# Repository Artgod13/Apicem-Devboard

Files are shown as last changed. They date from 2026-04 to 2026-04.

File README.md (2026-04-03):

# Description
The Apicem Devboard is a Devboard designed by me for Hack Club. Currently it uses a RP2040 MCU, USB-C Power, 16 Mb Flash Storage, Reset Button, Power Indication LED, and a Neo Pixel Status LED. The board was designed to handle 0.6 amps of power. All of these features were added with what is essential in a board in mind. This board was designed to be like a Pi-Pico but way beefier and look cooler. In theory it should be exactly the same dimensions as a Pi-Pico and it uses the same MCu as the Pi-Pico. This board is named "Apicem" as that's latin for "vertex" or "peak" showing how this board is the peak of it's kind.



## Schematic


## PCB





## 3D Images



## My Documented Journey
See [My Journal](./JOURNAL.md)

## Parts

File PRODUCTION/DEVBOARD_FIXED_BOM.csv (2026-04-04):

Designator | Footprint | Value | LCSC Part #
C1 | C_0402_1005Metric | 1uF | C15849
C2 | C_0402_1005Metric | 1uF | C15849
C3 | C_0402_1005Metric | 100nF | C1525
C4 | C_0402_1005Metric | 100nF | C1525
C5 | C_0402_1005Metric | 100nF | C1525
C6 | C_0402_1005Metric | 100nF | C1525
C7 | C_0402_1005Metric | 100nF | C1525
C8 | C_0402_1005Metric | 100nF | C1525
C9 | C_0402_1005Metric | 100nF | C1525
C10 | C_0402_1005Metric | 100nF | C1525
C11 | C_0402_1005Metric | 100nF | C1525
C12 | C_0402_1005Metric | 100nF | C1525
C13 | C_0402_1005Metric | 100nF | C1525
C14 | C_0402_1005Metric | 100nF | C1525
C15 | C_0402_1005Metric | 100nF | C1525
C16 | C_0402_1005Metric | 33pF | C1647
C17 | C_0402_1005Metric | 33pF | C1647
C18 | C_0603_1608Metric | 10uF | C19702
C19 | C_0603_1608Metric | 10uF | C19702
R1 | R_0402_1005Metric | 27 | C25190
R2 | R_0402_1005Metric | 27 | C25190
R3 | R_0402_1005Metric | 5.1K | C25905
R4 | R_0402_1005Metric | 5.1K | C25905
R5 | R_0402_1005Metric | 10K | C25804
R6 | R_0402_1005Metric | 10K | C25804
R7 | R_0402_1005Metric | 1K | C11702
R8 | R_0402_1005Metric | 1K | C11702
R9 | R_0603_1608Metric | 330 | C23138
D1 | LED_0603_1608Metric | LED | C72043
D2 | LED_SK6812MINI_PLCC4_3.5x3.5mm_P1.75mm | SK6812 | C2761795
SW1 | SW_Push_SPST_NO_Alps_SKRK | SW | C318884
SW2 | SW_Push_SPST_NO_Alps_SKRK | SW | C318884
U1 | QFN-56-1EP_7x7mm_P0.4mm_EP3.2x3.2mm | RP2040 | C2040
U2 | SOT-23-5 | AP2112K-3.3 | C51118
U3 | SOIC-8_5.3x5.3mm_P1.27mm | W25Q128JVS | C97521
U5 | SOT-666 | USBLC6-2P6 | C282765
Y1 | Crystal_SMD_3225-4Pin_3.2x2.5mm | 12MHz | C9002
# DO NOT ASSEMBLE (through-hole)
J1 | PinHeader_1x20_P2.54mm_Vertical | Conn
J2 | PinHeader_1x20_P2.54mm_Vertical | Conn
J3 | PinHeader_1x03_P2.54mm_Vertical | Conn
J4 | USB_C_Receptacle_HRO_TYPE-C-31-M-12 | USB_C | C165948

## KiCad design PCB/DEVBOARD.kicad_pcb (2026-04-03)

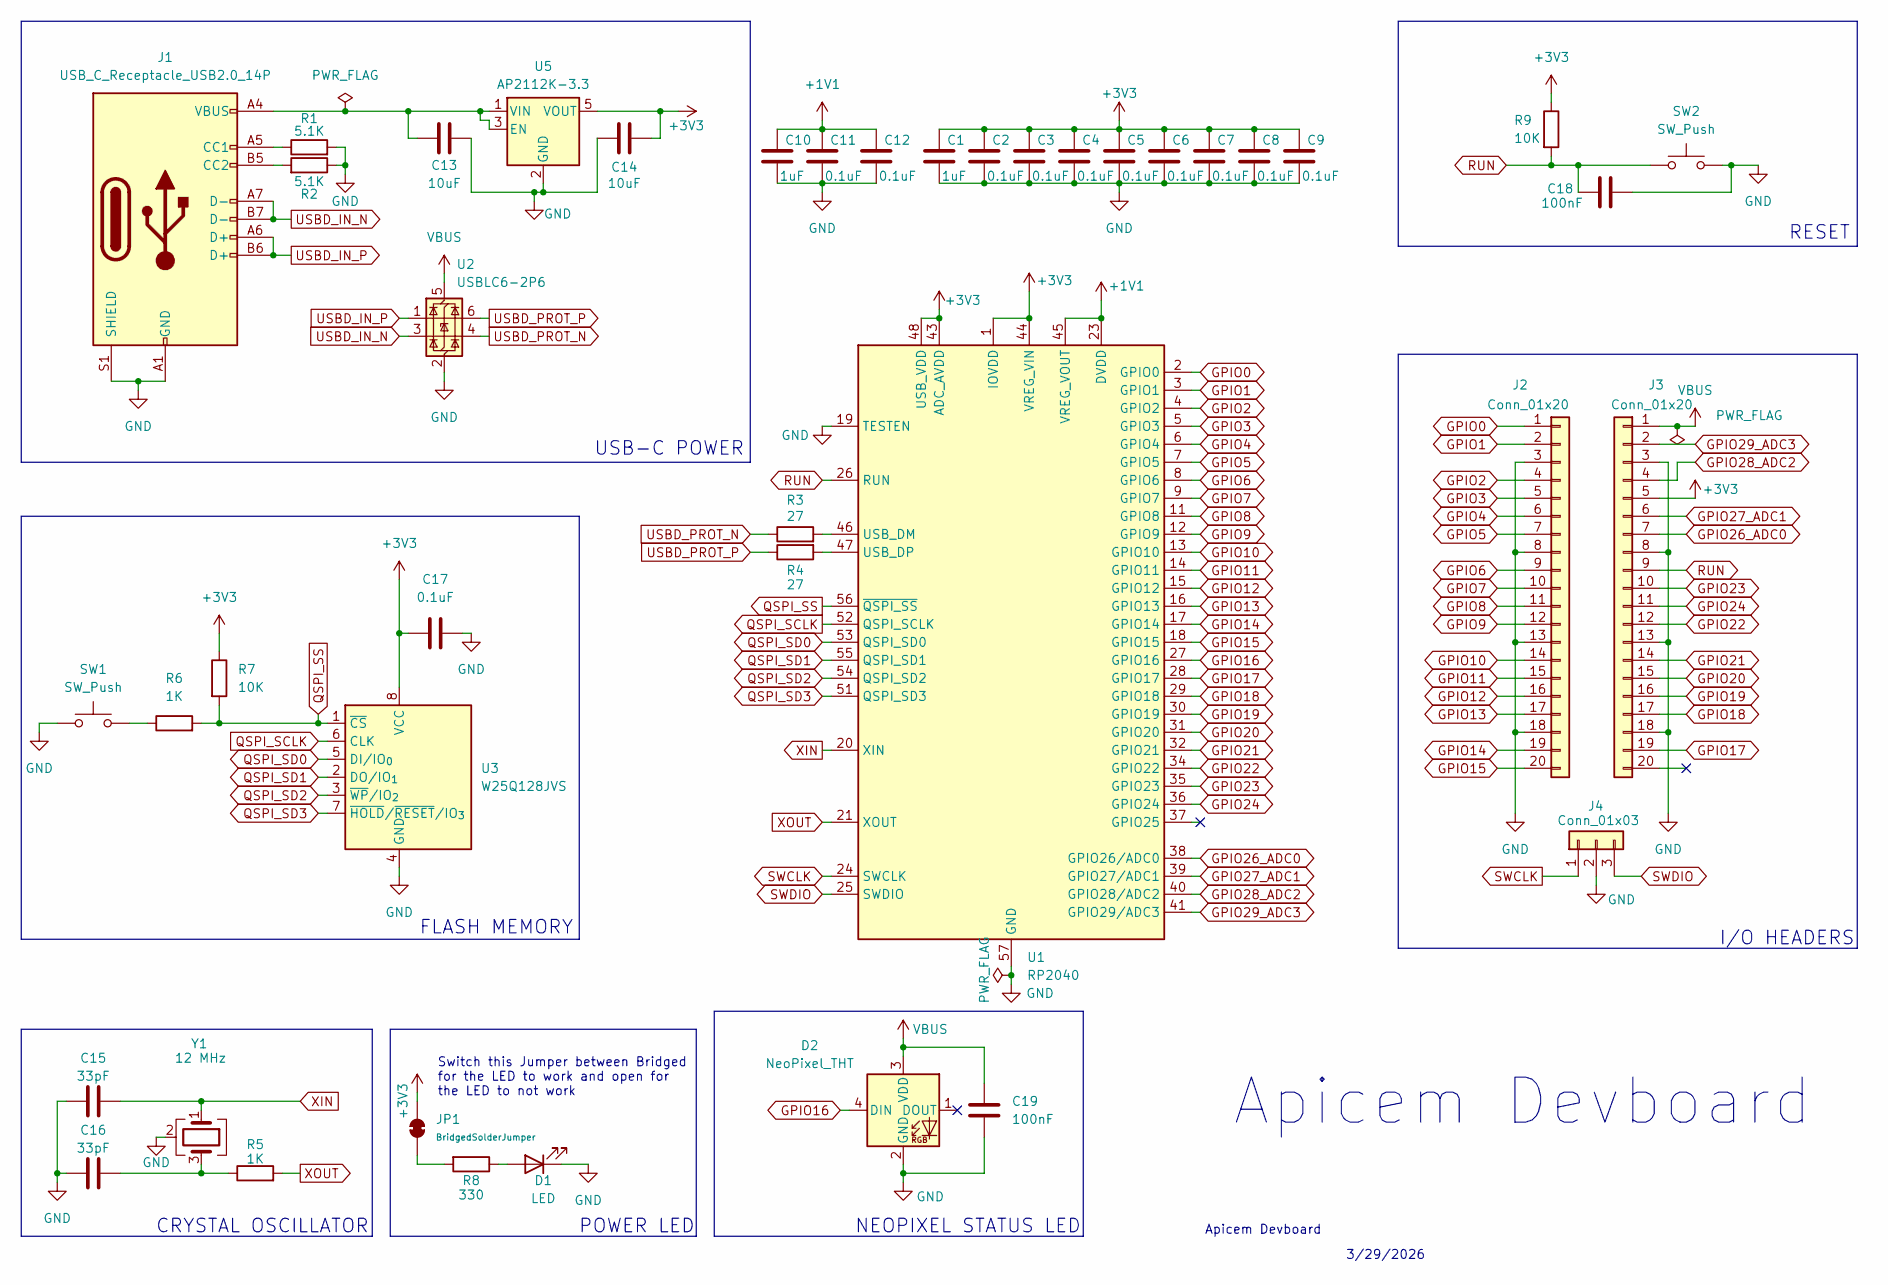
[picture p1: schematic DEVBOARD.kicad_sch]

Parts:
C1, C10: 1uF; C_0402_1005Metric
C2, C3, C4, C5, C6, C7, C8, C9, C11, C12, C17: 0.1uF; C_0402_1005Metric
C13, C14: 10uF; C_0603_1608Metric
C15, C16: 33pF; C_0402_1005Metric
C18, C19: 100nF; C_0402_1005Metric
D1: LED; LED_0603_1608Metric
D2: NeoPixel_THT; LED_SK6812MINI_PLCC4_3.5x3.5mm_P1.75mm
J1: USB_C_Receptacle_USB2.0_14P; USB_C_Receptacle_HRO_TYPE-C-31-M-12
J2, J3: Conn_01x20; PinHeader_1x20_P2.54mm_Vertical
J4: Conn_01x03; PinHeader_1x03_P2.54mm_Vertical
JP1: BridgedSolderJumper; SolderJumper-2_P1.3mm_Open_RoundedPad1.0x1.5mm
R1, R2: 5.1K; R_0402_1005Metric
R3, R4: 27; R_0402_1005Metric
R5, R6: 1K; R_0402_1005Metric
R7, R9: 10K; R_0402_1005Metric
R8: 330; R_0603_1608Metric
SW1, SW2: SW_Push; SW_Push_SPST_NO_Alps_SKRK
U1: RP2040; QFN-56-1EP_7x7mm_P0.4mm_EP3.2x3.2mm
U2: USBLC6-2P6; SOT-666
U3: W25Q128JVS; SOIC-8_5.3x5.3mm_P1.27mm
U5: AP2112K-3.3; SOT-23-5
Y1: 12 MHz; Crystal_SMD_3225-4Pin_3.2x2.5mm

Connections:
+1V1: C10.1, C11.1, C12.1, U1.23 (DVDD), U1.45 (VREG_VOUT), U1.50 (DVDD)
+3V3: C1.1, C2.1, C3.1, C4.1, C5.1, C6.1, C7.1, C8.1, C9.1, C14.2, C17.1, J3.5, JP1.2 (B), R7.1, R9.1, U1.1 (IOVDD), U1.10 (IOVDD), U1.22 (IOVDD), U1.33 (IOVDD), U1.42 (IOVDD), U1.43 (ADC_AVDD), U1.44 (VREG_VIN), U1.48 (USB_VDD), U1.49 (IOVDD), U3.8 (VCC), U5.5 (VOUT)
GND: C1.2, C2.2, C3.2, C4.2, C5.2, C6.2, C7.2, C8.2, C9.2, C10.2, C11.2, C12.2, C13.2, C14.1, C15.2, C16.2, C17.2, C18.2, C19.2, D1.1 (K), D2.2 (GND), J1.A1 (GND), J1.A12 (GND), J1.B1 (GND), J1.B12 (GND), J1.S1 (SHIELD), J2.3, J2.8, J2.13, J2.18, J3.3, J3.8, J3.13, J3.18, J4.2, R1.2, R2.1, SW1.1, SW2.2, U1.19 (TESTEN), U1.57 (GND), U2.2 (GND), U3.4 (GND), U5.2 (GND), Y1.2 (G), Y1.4 (G)
GPIO0: J2.1, U1.2 (GPIO0)
GPIO1: J2.2, U1.3 (GPIO1)
GPIO2: J2.4, U1.4 (GPIO2)
GPIO3: J2.5, U1.5 (GPIO3)
GPIO4: J2.6, U1.6 (GPIO4)
GPIO5: J2.7, U1.7 (GPIO5)
GPIO6: J2.9, U1.8 (GPIO6)
GPIO7: J2.10, U1.9 (GPIO7)
GPIO8: J2.11, U1.11 (GPIO8)
GPIO9: J2.12, U1.12 (GPIO9)
GPIO10: J2.14, U1.13 (GPIO10)
GPIO11: J2.15, U1.14 (GPIO11)
GPIO12: J2.16, U1.15 (GPIO12)
GPIO13: J2.17, U1.16 (GPIO13)
GPIO14: J2.19, U1.17 (GPIO14)
GPIO15: J2.20, U1.18 (GPIO15)
GPIO16: D2.4 (DIN), U1.27 (GPIO16)
GPIO17: J3.19, U1.28 (GPIO17)
GPIO18: J3.17, U1.29 (GPIO18)
GPIO19: J3.16, U1.30 (GPIO19)
GPIO20: J3.15, U1.31 (GPIO20)
GPIO21: J3.14, U1.32 (GPIO21)
GPIO22: J3.12, U1.34 (GPIO22)
GPIO23: J3.10, U1.35 (GPIO23)
GPIO24: J3.11, U1.36 (GPIO24)
GPIO26_ADC0: J3.7, U1.38 (GPIO26/ADC0)
GPIO27_ADC1: J3.6, U1.39 (GPIO27/ADC1)
GPIO28_ADC2: J3.4, U1.40 (GPIO28/ADC2)
GPIO29_ADC3: J3.2, U1.41 (GPIO29/ADC3)
unnamed: C16.1, R5.1, Y1.3
unnamed: D1.2 (A), R8.1
unnamed: J1.A5 (CC1), R1.1
unnamed: J1.B5 (CC2), R2.2
unnamed: JP1.1 (A), R8.2
unnamed: R6.1, SW1.2
unnamed: R3.2, U1.46 (USB_DM)
unnamed: R4.2, U1.47 (USB_DP)
unnamed: C13.1, J1.A4 (VBUS), J1.A9 (VBUS), J1.B4 (VBUS), J1.B9 (VBUS), U5.1 (VIN), U5.3 (EN)
QSPI_SCLK: U1.52 (QSPI_SCLK), U3.6 (CLK)
QSPI_SD0: U1.53 (QSPI_SD0), U3.5 (DI/IO_{0})
QSPI_SD1: U1.55 (QSPI_SD1), U3.2 (DO/IO_{1})
QSPI_SD2: U1.54 (QSPI_SD2), U3.3 (~WP/IO_{2})
QSPI_SD3: U1.51 (QSPI_SD3), U3.7 (~HOLD/~RESET/IO_{3})
QSPI_SS: R6.2, R7.2, U1.56 (~QSPI_SS), U3.1 (~CS)
RUN: C18.1, J3.9, R9.2, SW2.1, U1.26 (RUN)
SWCLK: J4.1, U1.24 (SWCLK)
SWDIO: J4.3, U1.25 (SWDIO)
USBD_IN_N: J1.A7 (D-), J1.B7 (D-), U2.3 (I/O2)
USBD_IN_P: J1.A6 (D+), J1.B6 (D+), U2.1 (I/O1)
USBD_PROT_N: R3.1, U2.4 (I/O2)
USBD_PROT_P: R4.1, U2.6 (I/O1)
VBUS: C19.1, D2.3 (VDD), J3.1, U2.5 (VBUS)
XIN: C15.1, U1.20 (XIN), Y1.1
XOUT: R5.2, U1.21 (XOUT)

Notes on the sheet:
Apicem Devboard
3/29/2026
I/O HEADERS
USB-C POWER
CRYSTAL OSCILLATOR
POWER LED
NEOPIXEL STATUS LED
FLASH MEMORY
Switch this Jumper between Bridged for the LED to work and open for the LED to not work
RESET

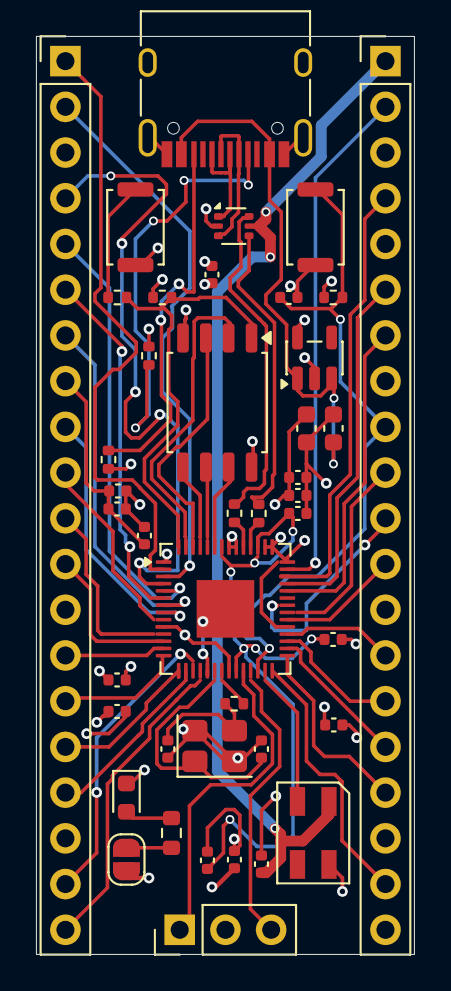
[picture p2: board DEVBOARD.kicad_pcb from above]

Board: 4 copper layers, 21.0 x 51.0 mm, 42 parts (0 on the bottom side), 57 nets.

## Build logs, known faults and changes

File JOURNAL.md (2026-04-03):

<!--
  This journal is auto generated by Stasis.
-->

# 3/30/2026 12 AM - Worked on final touches and thought of name/logo

_Time spent: 1.5h_

Well in the last update I had like 3 errors to fix but it was with the data lines in the middle of the mess so I first decided to move the data lines but then I thought how much of a mess it would be to do this while parts and wiring are all round it. So I decided to move the flash memory SMD to the left and move the wires corresponding with the memory around. So ultimately it worked and pased DRC. After this I started brainstoring names for the board when I came up with Apicem which is latin for "peak" or "vertex" in this case it's called that because this board is the peak of can be made really with such a board size. 














# 3/29/2026 10 PM - Continued PCB routing yet again and finished it

_Time spent: 2h_

I did a good amount of rewiring yet again and got every single one of the PCB components wired finally! This time I had to do a ton of rewiring as these final few vias's were super annoying and DRC did not like them so after mocing some resistors around and rewiring the back of the board they are all good. Also I started work on getting down the DRC warnings and errors down one by one as I had like 40 total and I am now down to like 10. I finally feel like I am getting close to reaching the end of the journey.







# 3/28/2026 2 AM - Still routing PCB improved some routes almost done

_Time spent: 1h_

In this session of work I continued working on the PCB as it's not fully wired yet and I have alot of compoments and parts on not alot of room so wiring is starting to get really difficult with tons of rewiring. In this one session I got a good amount of the GND and 3V3 Vias's out of the way. I rewired alot of the back as it did not have too much thought put into it and made it difficult to add more wiring to the back. 

 





# 3/2/2026 12 PM - Started routing PCB

_Time spent: 2h_

I started to route the PCB on my Devboard, currently I have all of the GPIO pins routed, the USB-C routed, the crystal routed, the buttons, and the LED. All I have left really to route is GND, 3v3, 1v1, and run. I also changed up the layout abit. 



# 3/1/2026 12 PM - PCB LAYOUT V1

_Time spent: 1.5h_

I made footprints for every single part and started working on a layout for PCB, Currently I'm trying to get an efficient design that also looks pretty good. currently I'm not too happy with this layout and want to make it more symmetrical and fix up some of that silkscreen.  




# 2/28/2026 10 PM - Fixed Schematic

_Time spent: 0.3h_

Well turns out I had a few errors in the schematic and even a short circuit!!! I used some power flags to satisfy ERC when it was buggin, and I spent a while pulling at my hair trying to figure out what's wrong with it, but it's all good now.



# 2/28/2026 9 PM - Finished Schematic V2

_Time spent: 2h_

Well Schematic V1 was lowk very boring imo so I locked in and added more components and upgraded some other ones like the voltage regulator so the board can now handle 0.6 amps instead of the old 0.25 amps. I added a BOOTSEL button so flashing firmware will be easier. I also added a NEOPIXEL status LED as seeing your boards status is always nice. I will prolly start working on the PCB now... 



# 2/27/2026 12 PM - Made Schematic V1

_Time spent: 4.2h_

Made the V1 schematic for my Devboard. Currently it has USB-C power, I might add in battery charging. This Devboard currently features a RP2040 with a 16 Mb flash storage, a reset button, and a LED to indicate power in the board. I'm currently pondering what sensors I might be able to add to the board. 
